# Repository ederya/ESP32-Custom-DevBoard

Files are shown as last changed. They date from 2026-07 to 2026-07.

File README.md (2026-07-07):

# ESP32-Based Custom PCB Design

This repository contains the custom schematics, PCB layout, and manufacturing files for an ESP32-based hardware project, designed entirely from scratch using Altium Designer.

## Board Preview

| 2D PCB Layout | 3D Render from Altium | Assembled PCB |
|:---:|:---:|:---:|
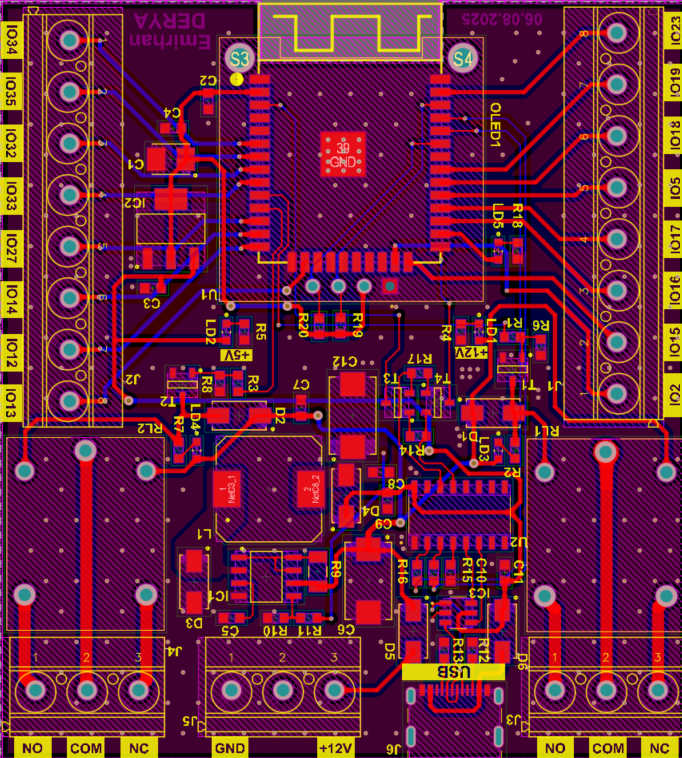
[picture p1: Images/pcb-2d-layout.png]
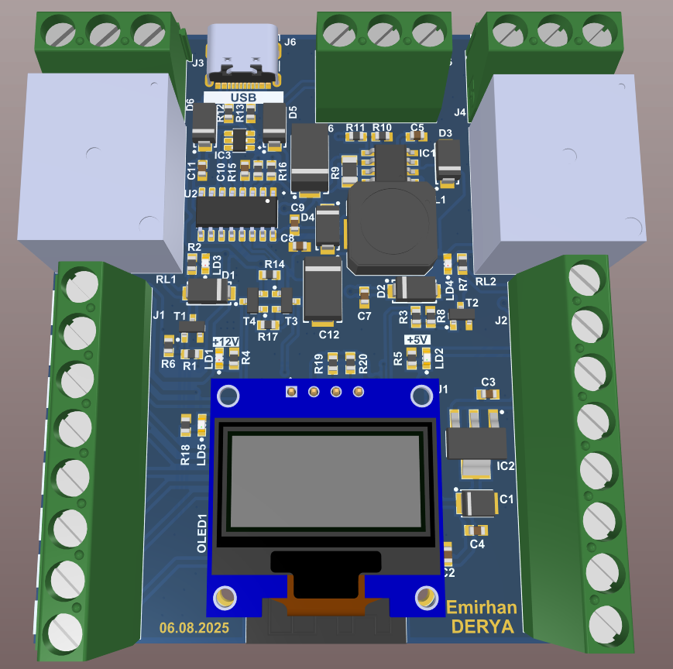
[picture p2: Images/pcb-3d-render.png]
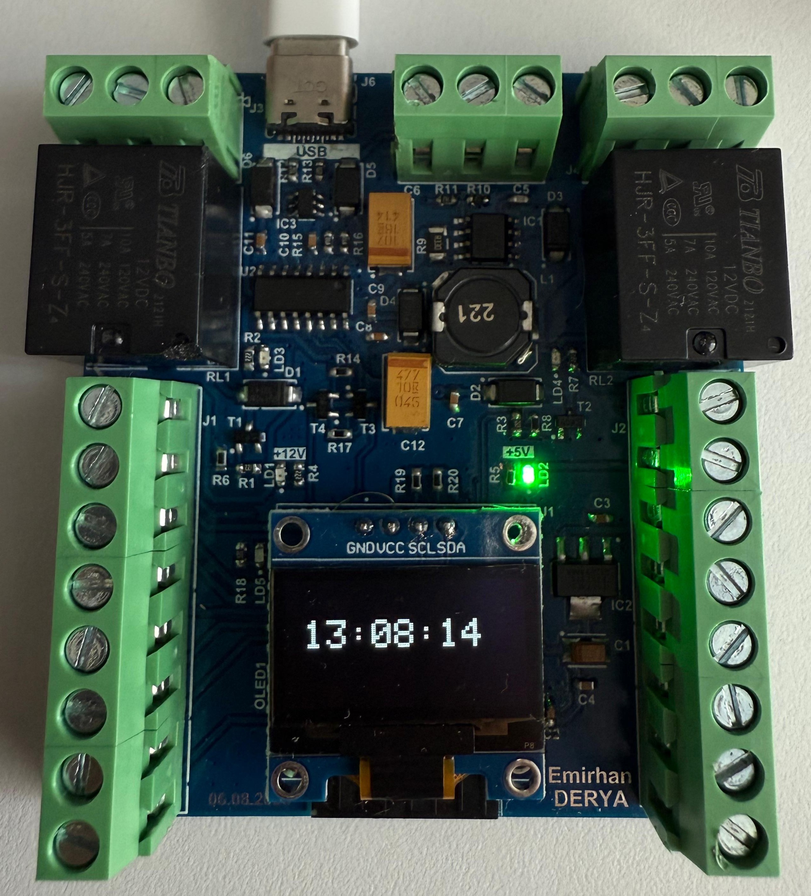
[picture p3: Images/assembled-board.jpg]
|  |  |  |

## Technical Specifications & Hardware Architecture

### Power Distribution & Management
* 12V DC input via secure industrial terminal blocks.
* High-efficiency switching regulator designed around the MC34063AD DC-DC Buck Converter for primary 12V to 5V regulation.
* An SPX1117-3.3 Low-Dropout (LDO) linear regulator for 5V to 3.3V logic power.
* ESD protection implemented on the USB data lines using a USBLC6 diode array.
* Standard flyback diodes placed across all 12V relay coils.
* 100nF and 100µF decoupling capacitors strategically placed.
* Strategic polygon pours for solid ground planes.

### Microcontroller & Peripherals
* Built around the ESP32-WROOM-32E module.
* Integrated CH340 chip handling the USB-to-UART bridge.
* A custom DTR/RTS auto-reset circuit utilizing BC817 NPN transistors.
* Mechanical 12V relays driven securely via BC817 NPN transistors.
* Dedicated I2C header connected to IO21 (SDA) and IO22 (SCL).

## Manufacturing Files
The repository includes all necessary production outputs in standard formats:
* Gerber files containing full fabrication layers.
* Bill of Materials (BOM) detailing the complete component list.
* NC Drill files providing precise drilling data.

## Schematic Document
The full logical circuit design can be reviewed here: [View Schematic PDF](ESP32_CustomBoard_Schematic.pdf)

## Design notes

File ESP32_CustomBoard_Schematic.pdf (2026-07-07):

Core.SchDoc

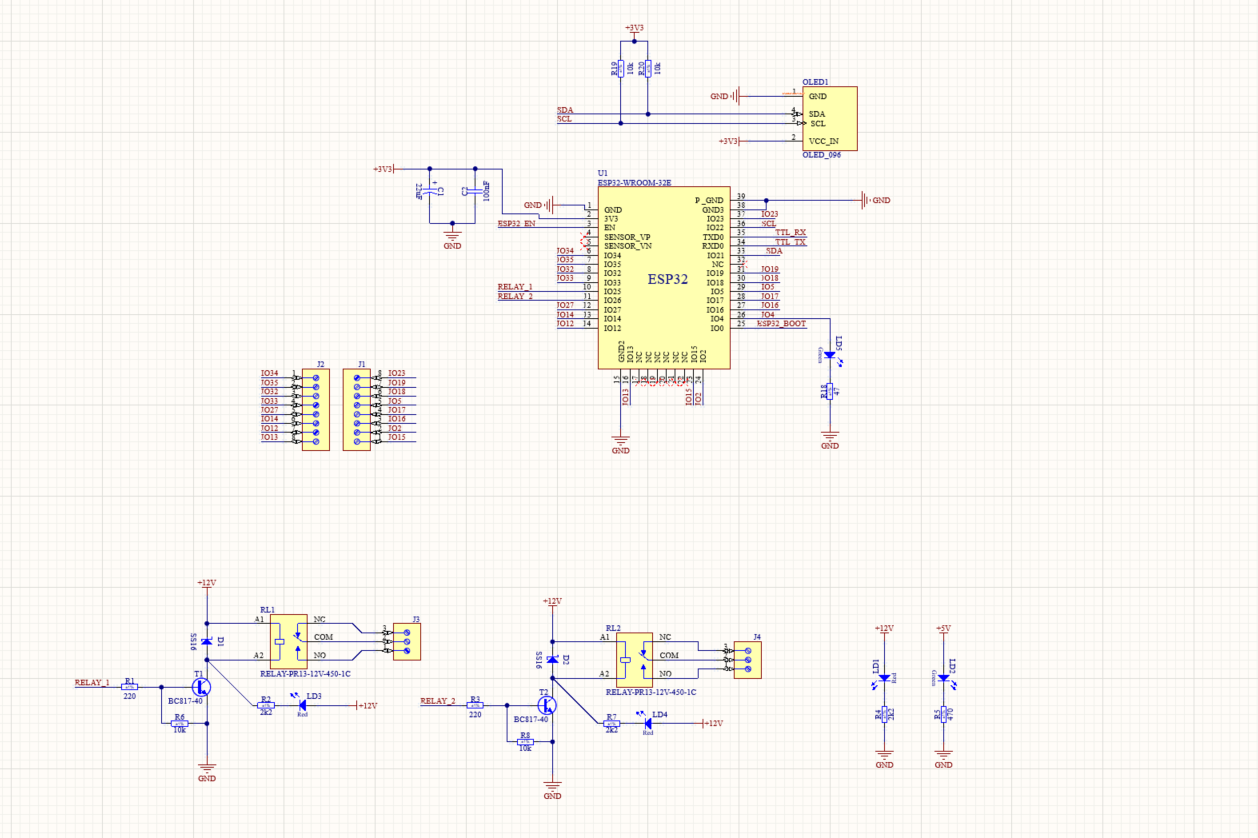
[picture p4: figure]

Power.SchDoc

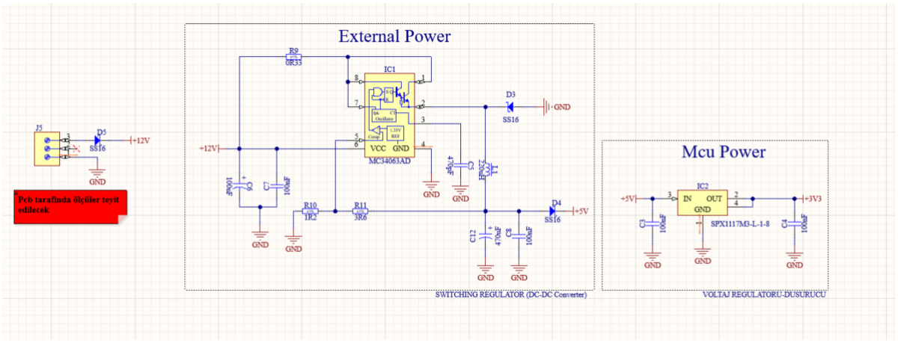
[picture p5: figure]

Com.SchDoc

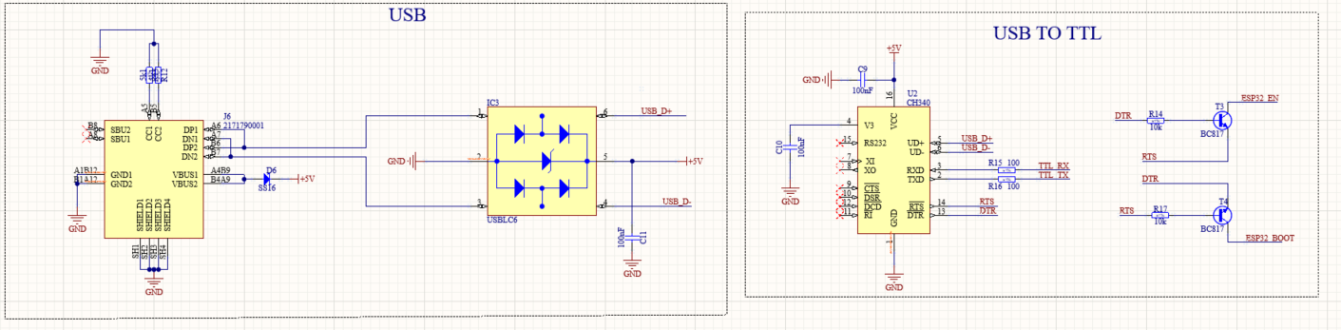
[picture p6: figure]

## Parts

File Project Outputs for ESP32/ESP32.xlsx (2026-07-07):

Line # | Name | Description | Designator | Quantity | Manufacturer 1 | Manufacturer Part Number 1 | Manufacturer Lifecycle 1 | Supplier 1 | Supplier Part Number 1 | Supplier Unit Price 1 | Supplier Subtotal 1
 | USBLC6 |  | IC3 | 1
 | 2171790001 |  | J6 | 1
 | OLED_096 |  | OLED1 | 1
 | RELAY-PR13-12V-450-1C |  | RL1, RL2 | 2
 | ESP32-WROOM-32E |  | U1 | 1
 | CH340 |  | U2 | 1
 | SPX1117M3-L-1-8 | 3-Terminal Regulator 1=GND 2=OUT 3=IN 4=OUT | IC2 | 1
 | MC34063AD | 3V to 40V 1.5A Peak Boost/Buck/Inverting Switching Regulator | IC1 | 1
 | 220uH | Inductor With Core | L1 | 1
 | Green | LED Green 1C 2A | LD2, LD5 | 2
 | Red | LED Red 1C 2A | LD1, LD3, LD4 | 3
 | 100nF | Non-polarised capacitor | C2, C3, C4, C7, C8, C9, C10, C11 | 8
 | 470pF | Non-polarised capacitor | C5 | 1
 | BC817-40 | NPN Transistor | T1, T2 | 2
 | BC817 | NPN Transistor | T3, T4 | 2
 | 22uF | Polarised capacitor | C1 | 1
 | 100uF | Polarised capacitor | C6 | 1
 | 470uF | Polarised capacitor | C12 | 1
 | 220 | Resistor - 1% | R1, R3 | 2
 | 2k2 | Resistor - 1% | R2, R4, R7 | 3
 | 470 | Resistor - 1% | R5 | 1
 | 10k | Resistor - 1% | R6, R8, R14, R17, R19, R20 | 6
 | 0R33 | Resistor - 1% | R9 | 1
 | 1R2 | Resistor - 1% | R10 | 1
 | 3R6 | Resistor - 1% | R11 | 1
 | 5k1 | Resistor - 1% | R12, R13 | 2
 | 100 | Resistor - 1% | R15, R16 | 2
 | 47 | Resistor - 1% | R18 | 1
 | SS16 | Schottky Diode | D1, D2, D3, D4, D5, D6 | 6
 |  | Terminal Block, 3 Positions, Screw Connection | J3, J4, J5 | 3
 |  | Terminal Block, 8 Positions, Screw Connection | J1, J2 | 2

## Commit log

2026-07-07 Initial commit: ESP32 Custom DevBoard
    [Com.SchDoc, Core.SchDoc, ESP32.PrjPcb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]
2026-07-07 2D PCB layout image and schematic file added
